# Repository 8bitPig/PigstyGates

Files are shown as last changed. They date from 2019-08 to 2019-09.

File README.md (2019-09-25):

# PigstyGates
teensy based USB-Midi to 24 Jack Gate Out

cc-by-nc-sa 4.0

v1:
Prototype failed! 
After about 2 weeks I stumbled upon the difference between the 74HC595 and 74HCT595.
Next Order will contain a 74HCT595 for retesting. 
Actually I have to guess, that the communication input levels are not enough for the 74HC595.
If this is not the Problem, I will retry with a line driver. 
v1 is still interesting for those who want a minimum part count and 0-5V Output levels. 
v1 code is still to do. Testcode is done and should work. To be shared after testing. 

v2:
-better layout
-correct part names and values
-got rid of SPI / using all 24 GPIO of the small size teensy boards
- TESTED AND WORKING :)
- ebay ADUM3160 USB Isolator since today was only working in theory. <- PROOVED!!!! :) 
- I sent in a sequence with 50% pulse cycle and 1/128 notes at a speed of 120 BPM in all 24 notes simultanously for testing without laggs on a teensy LC.
- code can't be simpler I guess. ^^

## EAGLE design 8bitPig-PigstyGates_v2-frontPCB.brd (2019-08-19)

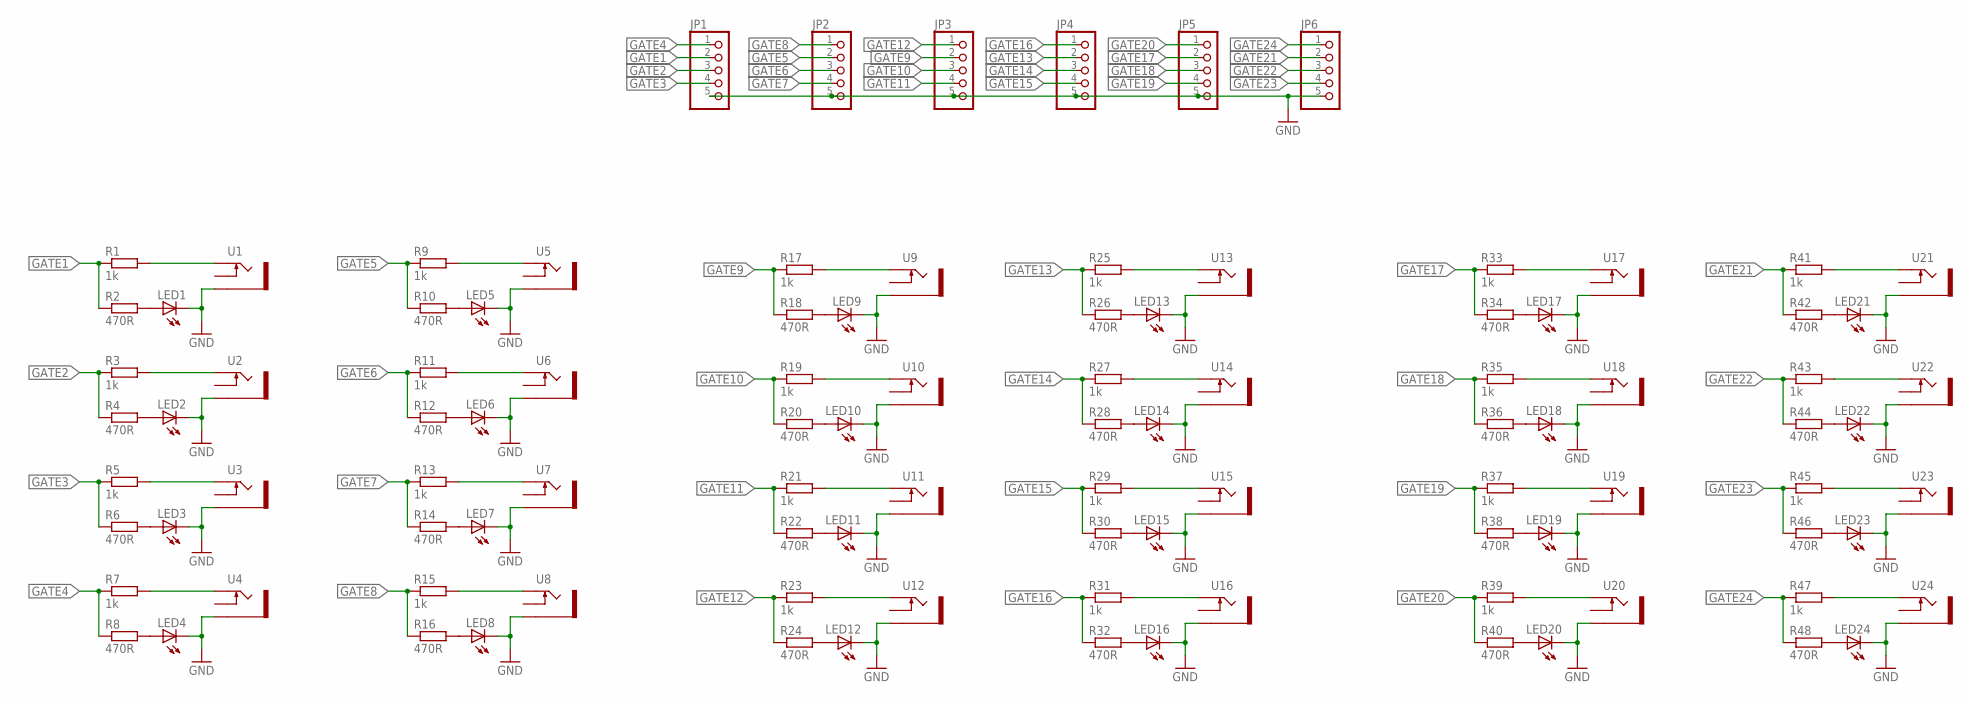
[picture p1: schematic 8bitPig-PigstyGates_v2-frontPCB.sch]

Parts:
JP1, JP2, JP3, JP4, JP5, JP6: PINHD-1X5; 1X05
LED1, LED2, LED3, LED4, LED5, LED6, LED7, LED8, LED9, LED10, LED11, LED12, LED13, LED14, LED15, LED16, LED17, LED18, LED19, LED20, LED21, LED22, LED23, LED24: LED3MM
R1, R3, R5, R7, R9, R11, R13, R15, R17, R19, R21, R23, R25, R27, R29, R31, R33, R35, R37, R39, R41, R43, R45, R47: 1k; R0603
R2, R4, R6, R8, R10, R12, R14, R16, R18, R20, R22, R24, R26, R28, R30, R32, R34, R36, R38, R40, R42, R44, R46, R48: 470R; R0603
U1, U2, U3, U4, U5, U6, U7, U8, U9, U10, U11, U12, U13, U14, U15, U16, U17, U18, U19, U20, U21, U22, U23, U24: THONKICONNNEW; WQP-PJ301M-12_JACK

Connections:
GATE1: JP1.2, R1.1, R2.1
GATE2: JP1.3, R3.1, R4.1
GATE3: JP1.4, R5.1, R6.1
GATE4: JP1.1, R7.1, R8.1
GATE5: JP2.2, R9.1, R10.1
GATE6: JP2.3, R11.1, R12.1
GATE7: JP2.4, R13.1, R14.1
GATE8: JP2.1, R15.1, R16.1
GATE9: JP3.2, R17.1, R18.1
GATE10: JP3.3, R19.1, R20.1
GATE11: JP3.4, R21.1, R22.1
GATE12: JP3.1, R23.1, R24.1
GATE13: JP4.2, R25.1, R26.1
GATE14: JP4.3, R27.1, R28.1
GATE15: JP4.4, R29.1, R30.1
GATE16: JP4.1, R31.1, R32.1
GATE17: JP5.2, R33.1, R34.1
GATE18: JP5.3, R35.1, R36.1
GATE19: JP5.4, R37.1, R38.1
GATE20: JP5.1, R39.1, R40.1
GATE21: JP6.2, R41.1, R42.1
GATE22: JP6.3, R43.1, R44.1
GATE23: JP6.4, R45.1, R46.1
GATE24: JP6.1, R47.1, R48.1
GND: JP1.5, JP2.5, JP3.5, JP4.5, JP5.5, JP6.5, LED1.K (C), LED2.K (C), LED3.K (C), LED4.K (C), LED5.K (C), LED6.K (C), LED7.K (C), LED8.K (C), LED9.K (C), LED10.K (C), LED11.K (C), LED12.K (C), LED13.K (C), LED14.K (C), LED15.K (C), LED16.K (C), LED17.K (C), LED18.K (C), LED19.K (C), LED20.K (C), LED21.K (C), LED22.K (C), LED23.K (C), LED24.K (C), U1.P$3_SLEEVE (SLEEVE), U2.P$3_SLEEVE (SLEEVE), U3.P$3_SLEEVE (SLEEVE), U4.P$3_SLEEVE (SLEEVE), U5.P$3_SLEEVE (SLEEVE), U6.P$3_SLEEVE (SLEEVE), U7.P$3_SLEEVE (SLEEVE), U8.P$3_SLEEVE (SLEEVE), U9.P$3_SLEEVE (SLEEVE), U10.P$3_SLEEVE (SLEEVE), U11.P$3_SLEEVE (SLEEVE), U12.P$3_SLEEVE (SLEEVE), U13.P$3_SLEEVE (SLEEVE), U14.P$3_SLEEVE (SLEEVE), U15.P$3_SLEEVE (SLEEVE), U16.P$3_SLEEVE (SLEEVE), U17.P$3_SLEEVE (SLEEVE), U18.P$3_SLEEVE (SLEEVE), U19.P$3_SLEEVE (SLEEVE), U20.P$3_SLEEVE (SLEEVE), U21.P$3_SLEEVE (SLEEVE), U22.P$3_SLEEVE (SLEEVE), U23.P$3_SLEEVE (SLEEVE), U24.P$3_SLEEVE (SLEEVE)
unnamed: LED1.A, R2.2
unnamed: R1.2, U1.P$1_TIP (TIP)
unnamed: LED2.A, R4.2
unnamed: R3.2, U2.P$1_TIP (TIP)
unnamed: LED3.A, R6.2
unnamed: R5.2, U3.P$1_TIP (TIP)
unnamed: LED4.A, R8.2
unnamed: R7.2, U4.P$1_TIP (TIP)
unnamed: LED5.A, R10.2
unnamed: R9.2, U5.P$1_TIP (TIP)
unnamed: LED6.A, R12.2
unnamed: R11.2, U6.P$1_TIP (TIP)
unnamed: LED7.A, R14.2
unnamed: R13.2, U7.P$1_TIP (TIP)
unnamed: LED8.A, R16.2
unnamed: R15.2, U8.P$1_TIP (TIP)
unnamed: LED9.A, R18.2
unnamed: R17.2, U9.P$1_TIP (TIP)
unnamed: LED10.A, R20.2
unnamed: R19.2, U10.P$1_TIP (TIP)
unnamed: LED11.A, R22.2
unnamed: R21.2, U11.P$1_TIP (TIP)
unnamed: LED12.A, R24.2
unnamed: R23.2, U12.P$1_TIP (TIP)
unnamed: LED13.A, R26.2
unnamed: R25.2, U13.P$1_TIP (TIP)
unnamed: LED14.A, R28.2
unnamed: R27.2, U14.P$1_TIP (TIP)
unnamed: LED15.A, R30.2
unnamed: R29.2, U15.P$1_TIP (TIP)
unnamed: LED17.A, R34.2
unnamed: R33.2, U17.P$1_TIP (TIP)
unnamed: LED16.A, R32.2
unnamed: R31.2, U16.P$1_TIP (TIP)
unnamed: LED18.A, R36.2
unnamed: R35.2, U18.P$1_TIP (TIP)
unnamed: LED19.A, R38.2
unnamed: R37.2, U19.P$1_TIP (TIP)
unnamed: LED20.A, R40.2
unnamed: R39.2, U20.P$1_TIP (TIP)
unnamed: LED21.A, R42.2
unnamed: R41.2, U21.P$1_TIP (TIP)
unnamed: LED22.A, R44.2
unnamed: R43.2, U22.P$1_TIP (TIP)
unnamed: LED23.A, R46.2
unnamed: R45.2, U23.P$1_TIP (TIP)
unnamed: LED24.A, R48.2
unnamed: R47.2, U24.P$1_TIP (TIP)

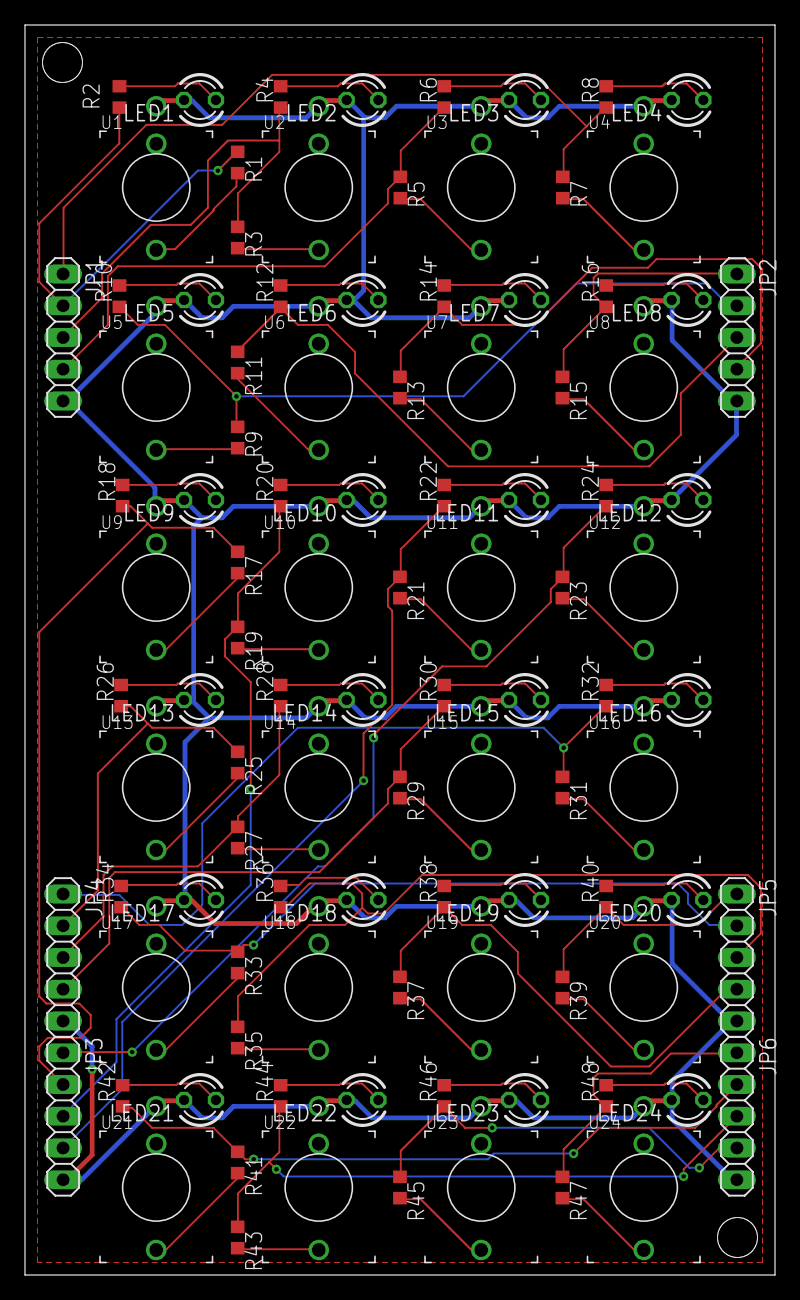
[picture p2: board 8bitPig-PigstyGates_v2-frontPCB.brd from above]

Board: 2 copper layers, 60.0 x 100.0 mm, 102 parts (0 on the bottom side), 73 nets.

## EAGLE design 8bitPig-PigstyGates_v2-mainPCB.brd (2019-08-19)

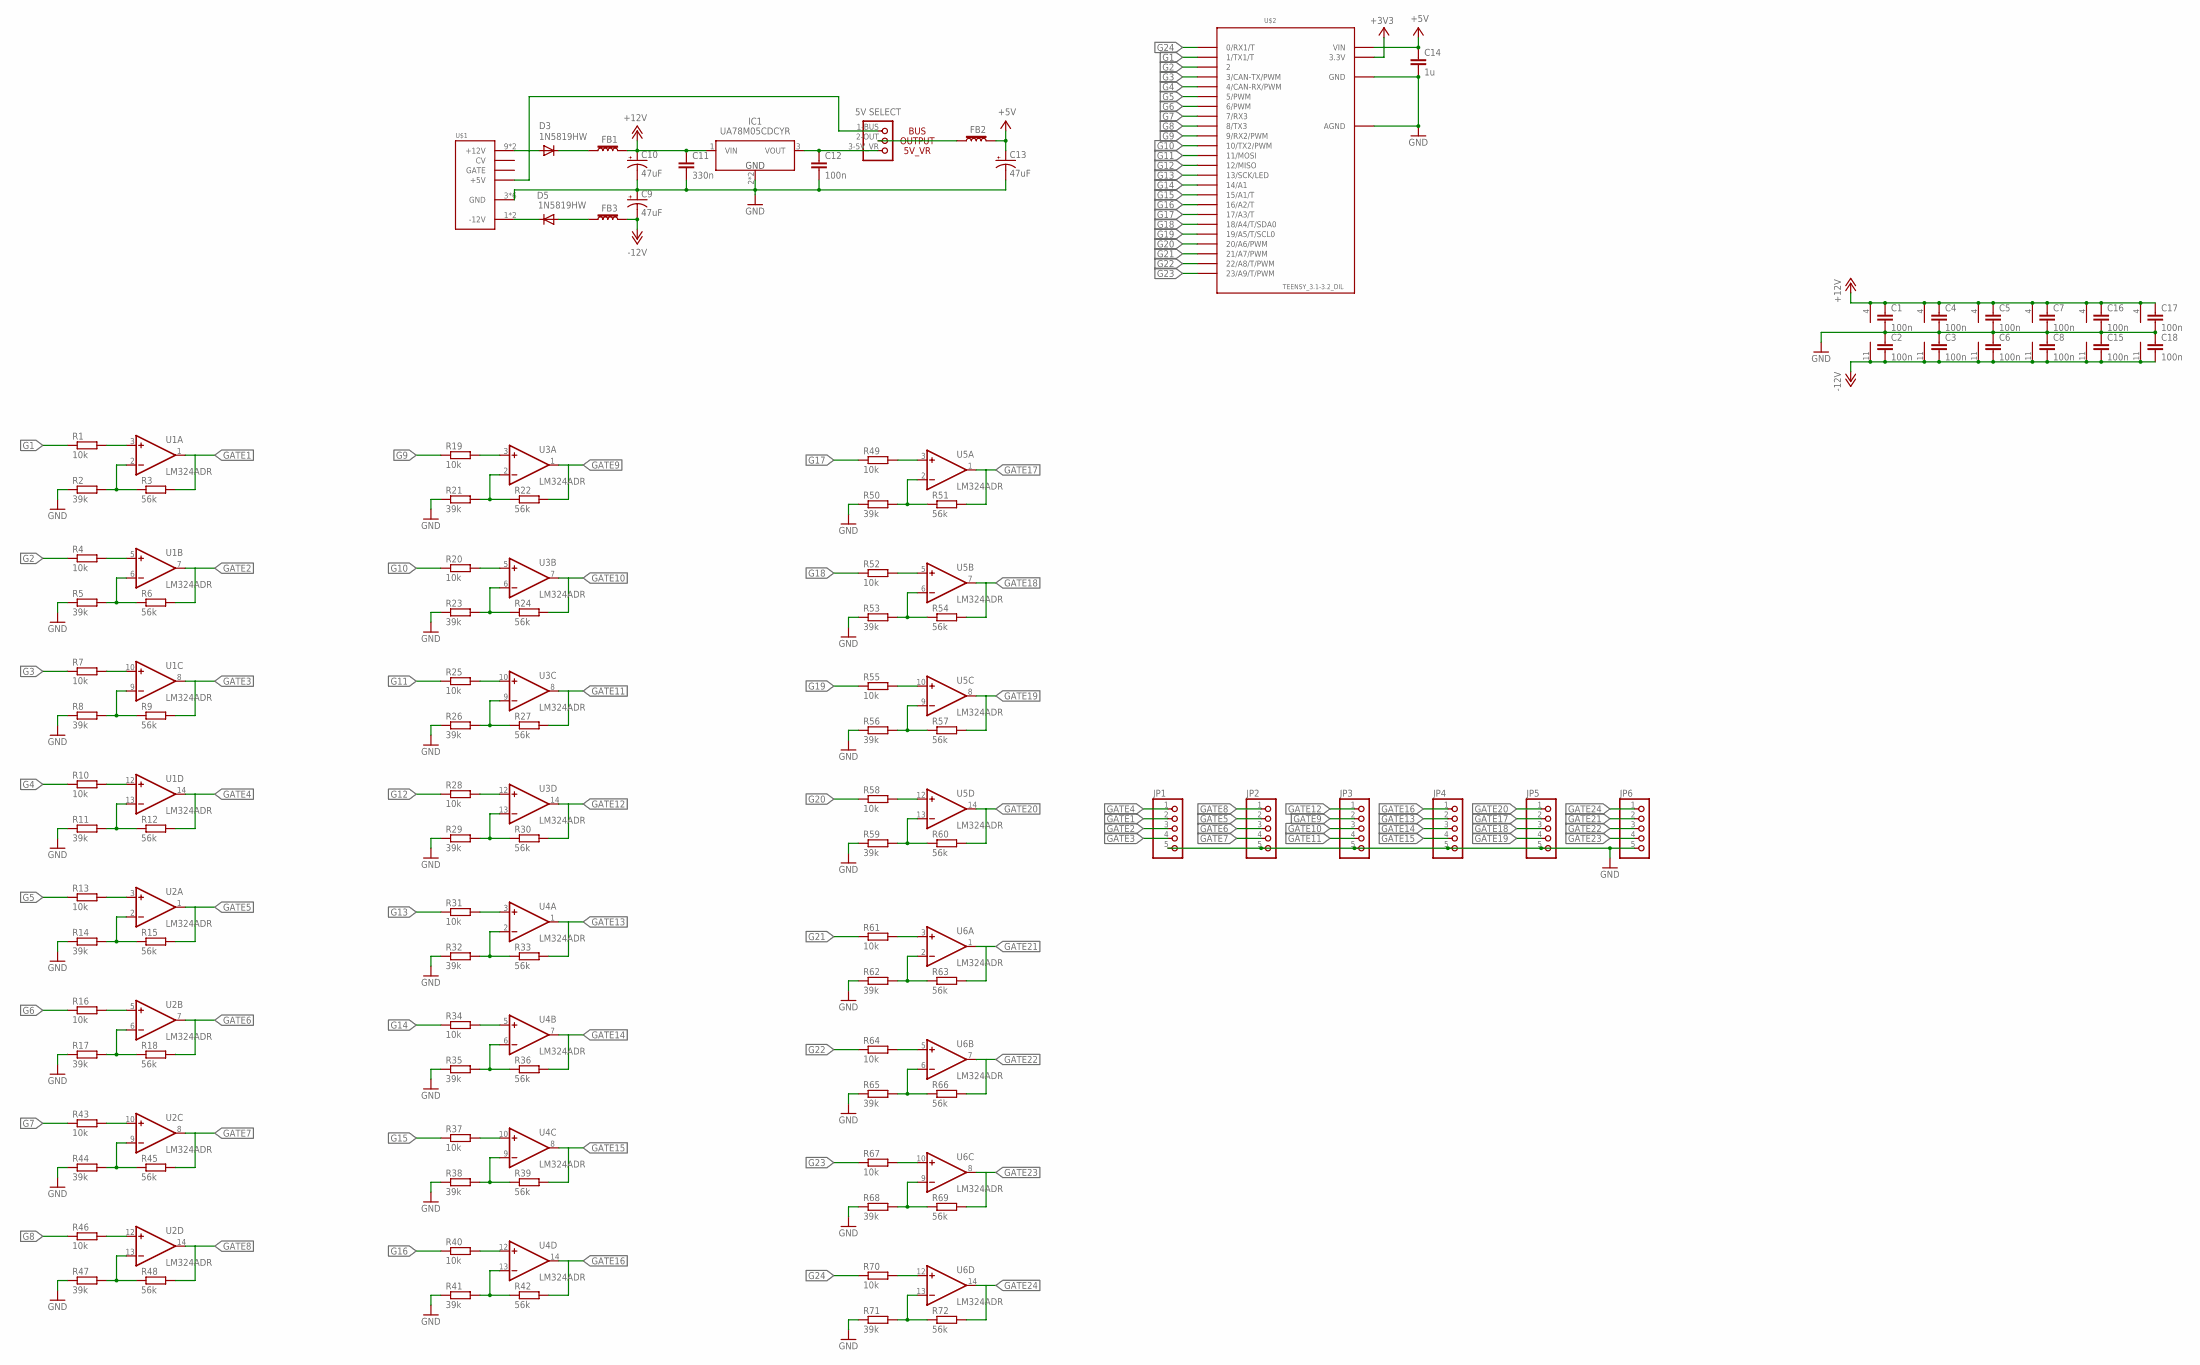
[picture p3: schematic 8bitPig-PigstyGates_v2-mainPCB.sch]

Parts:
C1, C2, C3, C4, C5, C6, C7, C8, C12, C15, C16, C17, C18: 100n; C0603
C9, C10, C13: 47uF; PANASONIC_D
C11: 330n; C0603
C14: 1u; C0603
D3, D5: 1N5819HW; DIODE_SOD123
FB1, FB2, FB3: 30Ω/1.8A; 0603
IC1: UA78M05CDCYR; SOT230P700X180-4N
JP1, JP2, JP3, JP4, JP5, JP6: PINHD-1X5; 1X05
JP_5V: SELECTOR_POWER
R1, R4, R7, R10, R13, R16, R19, R20, R25, R28, R31, R34, R37, R40, R43, R46, R49, R52, R55, R58, R61, R64, R67, R70: 10k; R0603
R2, R5, R8, R11, R14, R17, R21, R23, R26, R29, R32, R35, R38, R41, R44, R47, R50, R53, R56, R59, R62, R65, R68, R71: 39k; R0603
R3, R6, R9, R12, R15, R18, R22, R24, R27, R30, R33, R36, R39, R42, R45, R48, R51, R54, R57, R60, R63, R66, R69, R72: 56k; R0603
U1, U2, U3, U4, U5, U6: LM324ADR; SO14
U$1: POWER; POWER_16
U$2: TEENSY_3.1-3.2_DIL; TEENSY_3.0-3.2&LC_DIL

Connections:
+3V3: U$2.3.3V
+5V: C13.+, C14.1, FB2.2, U$2.VIN
+12V: C1.1, C4.1, C5.1, C7.1, C10.+, C11.1, C16.1, C17.1, FB1.2, IC1.1 (VIN), U1.4 (V+), U2.4 (V+), U3.4 (V+), U4.4 (V+), U5.4 (V+), U6.4 (V+)
-12V: C2.2, C3.2, C6.2, C8.2, C9.-, C15.2, C18.2, FB3.2, U1.11 (V-), U2.11 (V-), U3.11 (V-), U4.11 (V-), U5.11 (V-), U6.11 (V-)
G1: R1.1, U$2.1 (1/TX1/T)
G2: R4.1, U$2.2
G3: R7.1, U$2.3 (3/CAN-TX/PWM)
G4: R10.1, U$2.4 (4/CAN-RX/PWM)
G5: R13.1, U$2.5 (5/PWM)
G6: R16.1, U$2.6 (6/PWM)
G7: R43.1, U$2.7 (7/RX3)
G8: R46.1, U$2.8 (8/TX3)
G9: R19.1, U$2.9 (9/RX2/PWM)
G10: R20.1, U$2.10 (10/TX2/PWM)
G11: R25.1, U$2.11 (11/MOSI)
G12: R28.1, U$2.12 (12/MISO)
G13: R31.1, U$2.13 (13/SCK/LED)
G14: R34.1, U$2.14/A0 (14/A1)
G15: R37.1, U$2.15/A1 (15/A1/T)
G16: R40.1, U$2.16/A2 (16/A2/T)
G17: R49.1, U$2.17/A3 (17/A3/T)
G18: R52.1, U$2.18/A4 (18/A4/T/SDA0)
G19: R55.1, U$2.19/A5 (19/A5/T/SCL0)
G20: R58.1, U$2.20/A6 (20/A6/PWM)
G21: R61.1, U$2.21/A7 (21/A7/PWM)
G22: R64.1, U$2.22/A8 (22/A8/T/PWM)
G23: R67.1, U$2.23/A9 (23/A9/T/PWM)
G24: R70.1, U$2.0 (0/RX1/T)
GATE1: JP1.2, R3.2, U1.1 (OUT)
GATE2: JP1.3, R6.2, U1.7 (OUT)
GATE3: JP1.4, R9.2, U1.8 (OUT)
GATE4: JP1.1, R12.2, U1.14 (OUT)
GATE5: JP2.2, R15.2, U2.1 (OUT)
GATE6: JP2.3, R18.2, U2.7 (OUT)
GATE7: JP2.4, R45.2, U2.8 (OUT)
GATE8: JP2.1, R48.2, U2.14 (OUT)
GATE9: JP3.2, R22.2, U3.1 (OUT)
GATE10: JP3.3, R24.2, U3.7 (OUT)
GATE11: JP3.4, R27.2, U3.8 (OUT)
GATE12: JP3.1, R30.2, U3.14 (OUT)
GATE13: JP4.2, R33.2, U4.1 (OUT)
GATE14: JP4.3, R36.2, U4.7 (OUT)
GATE15: JP4.4, R39.2, U4.8 (OUT)
GATE16: JP4.1, R42.2, U4.14 (OUT)
GATE17: JP5.2, R51.2, U5.1 (OUT)
GATE18: JP5.3, R54.2, U5.7 (OUT)
GATE19: JP5.4, R57.2, U5.8 (OUT)
GATE20: JP5.1, R60.2, U5.14 (OUT)
GATE21: JP6.2, R63.2, U6.1 (OUT)
GATE22: JP6.3, R66.2, U6.7 (OUT)
GATE23: JP6.4, R69.2, U6.8 (OUT)
GATE24: JP6.1, R72.2, U6.14 (OUT)
GND: C1.2, C2.1, C3.1, C4.2, C5.2, C6.1, C7.2, C8.1, C9.+, C10.-, C11.2, C12.2, C13.-, C14.2, C15.1, C16.2, C17.2, C18.1, IC1.2 (GND), IC1.4 (GND), JP1.5, JP2.5, JP3.5, JP4.5, JP5.5, JP6.5, R2.1, R5.1, R8.1, R11.1, R14.1, R17.1, R21.1, R23.1, R26.1, R29.1, R32.1, R35.1, R38.1, R41.1, R44.1, R47.1, R50.1, R53.1, R56.1, R59.1, R62.1, R65.1, R68.1, R71.1, U$1.3 (GND), U$1.4 (GND), U$1.5 (GND), U$1.6 (GND), U$1.7 (GND), U$1.8 (GND), U$2.AGND, U$2.GND
unnamed: R1.2, U1.3 (+IN)
unnamed: R2.2, R3.1, U1.2 (-IN)
unnamed: R4.2, U1.5 (+IN)
unnamed: R5.2, R6.1, U1.6 (-IN)
unnamed: R7.2, U1.10 (+IN)
unnamed: R8.2, R9.1, U1.9 (-IN)
unnamed: R10.2, U1.12 (+IN)
unnamed: R11.2, R12.1, U1.13 (-IN)
unnamed: D3.A, U$1.9 (+12V), U$1.10 (+12V)
unnamed: D5.C, U$1.1 (-12V), U$1.2 (-12V)
unnamed: D5.A, FB3.1
unnamed: D3.C, FB1.1
unnamed: JP_5V.1-BUS, U$1.11 (+5V), U$1.12 (+5V)
unnamed: C12.1, IC1.3 (VOUT), JP_5V.3-5V_VR (3-VR)
unnamed: FB2.1, JP_5V.2-OUT
unnamed: R13.2, U2.3 (+IN)
unnamed: R19.2, U3.3 (+IN)
unnamed: R20.2, U3.5 (+IN)
unnamed: R21.2, R22.1, U3.2 (-IN)
unnamed: R23.2, R24.1, U3.6 (-IN)
unnamed: R25.2, U3.10 (+IN)
unnamed: R26.2, R27.1, U3.9 (-IN)
unnamed: R28.2, U3.12 (+IN)
unnamed: R29.2, R30.1, U3.13 (-IN)
unnamed: R31.2, U4.3 (+IN)
unnamed: R32.2, R33.1, U4.2 (-IN)
unnamed: R34.2, U4.5 (+IN)
unnamed: R35.2, R36.1, U4.6 (-IN)
unnamed: R37.2, U4.10 (+IN)
unnamed: R38.2, R39.1, U4.9 (-IN)
unnamed: R40.2, U4.12 (+IN)
unnamed: R41.2, R42.1, U4.13 (-IN)
unnamed: R14.2, R15.1, U2.2 (-IN)
unnamed: R16.2, U2.5 (+IN)
unnamed: R17.2, R18.1, U2.6 (-IN)
unnamed: R43.2, U2.10 (+IN)
unnamed: R44.2, R45.1, U2.9 (-IN)
unnamed: R46.2, U2.12 (+IN)
unnamed: R47.2, R48.1, U2.13 (-IN)
unnamed: R49.2, U5.3 (+IN)
unnamed: R50.2, R51.1, U5.2 (-IN)
unnamed: R52.2, U5.5 (+IN)
unnamed: R53.2, R54.1, U5.6 (-IN)
unnamed: R55.2, U5.10 (+IN)
unnamed: R56.2, R57.1, U5.9 (-IN)
unnamed: R58.2, U5.12 (+IN)
unnamed: R59.2, R60.1, U5.13 (-IN)
unnamed: R61.2, U6.3 (+IN)
unnamed: R62.2, R63.1, U6.2 (-IN)
unnamed: R64.2, U6.5 (+IN)
unnamed: R65.2, R66.1, U6.6 (-IN)
unnamed: R67.2, U6.10 (+IN)
unnamed: R68.2, R69.1, U6.9 (-IN)
unnamed: R70.2, U6.12 (+IN)
unnamed: R71.2, R72.1, U6.13 (-IN)

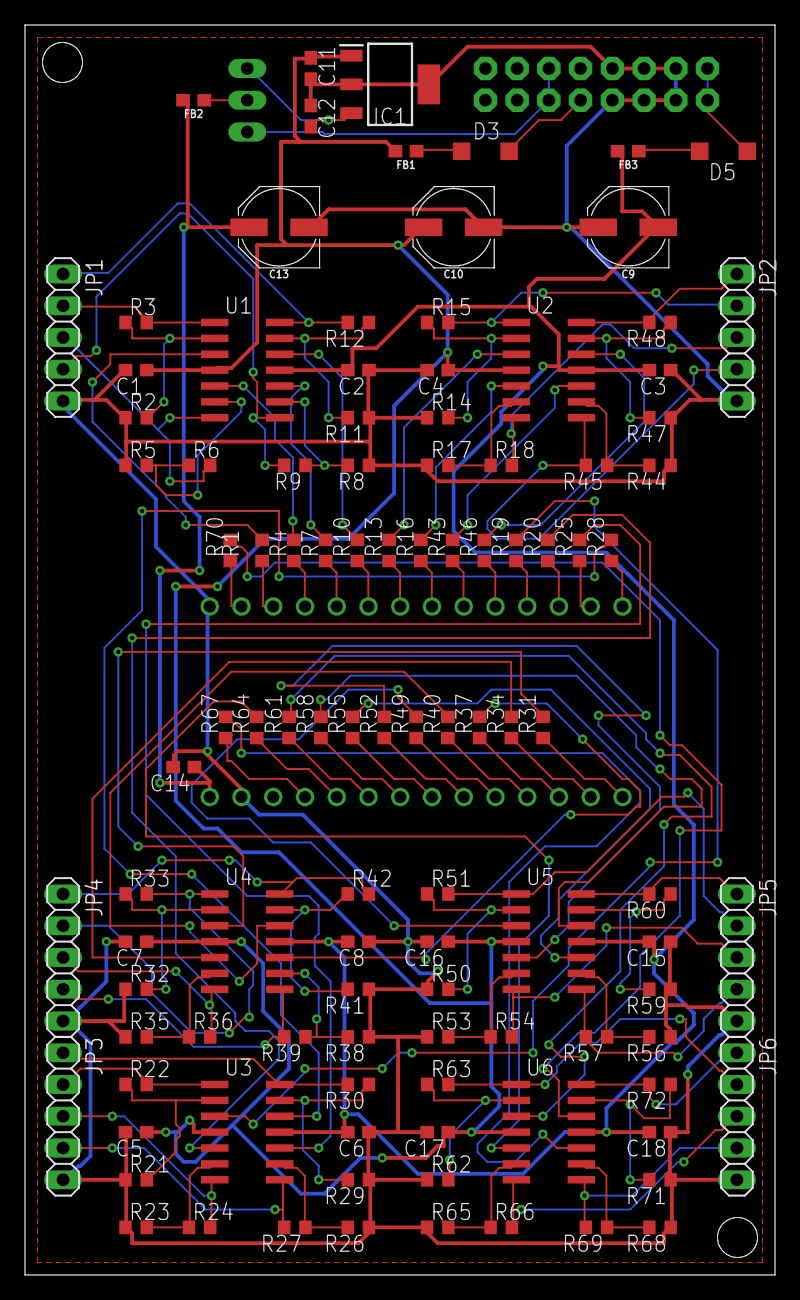
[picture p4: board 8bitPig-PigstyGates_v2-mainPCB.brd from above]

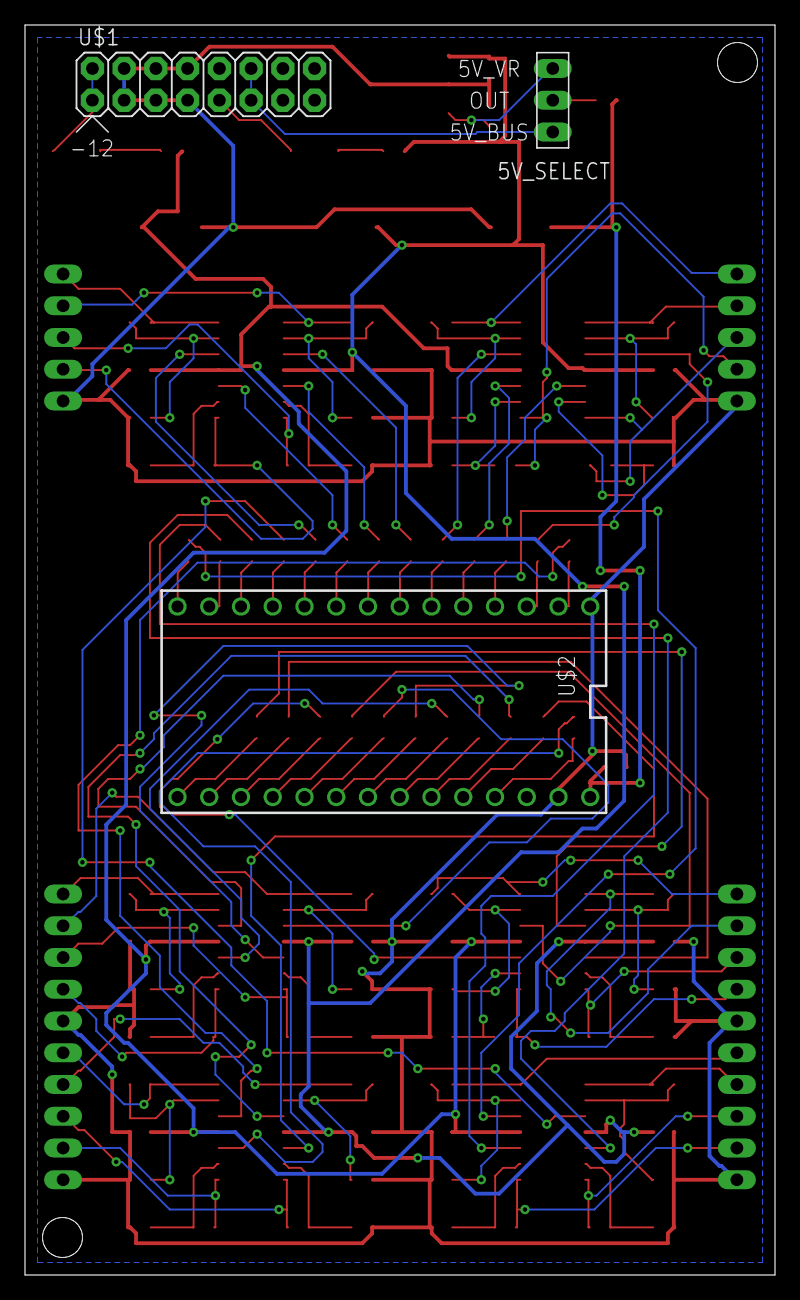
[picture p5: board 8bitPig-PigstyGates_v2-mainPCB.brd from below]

Board: 2 copper layers, 60.0 x 100.0 mm, 111 parts (3 on the bottom side), 107 nets.

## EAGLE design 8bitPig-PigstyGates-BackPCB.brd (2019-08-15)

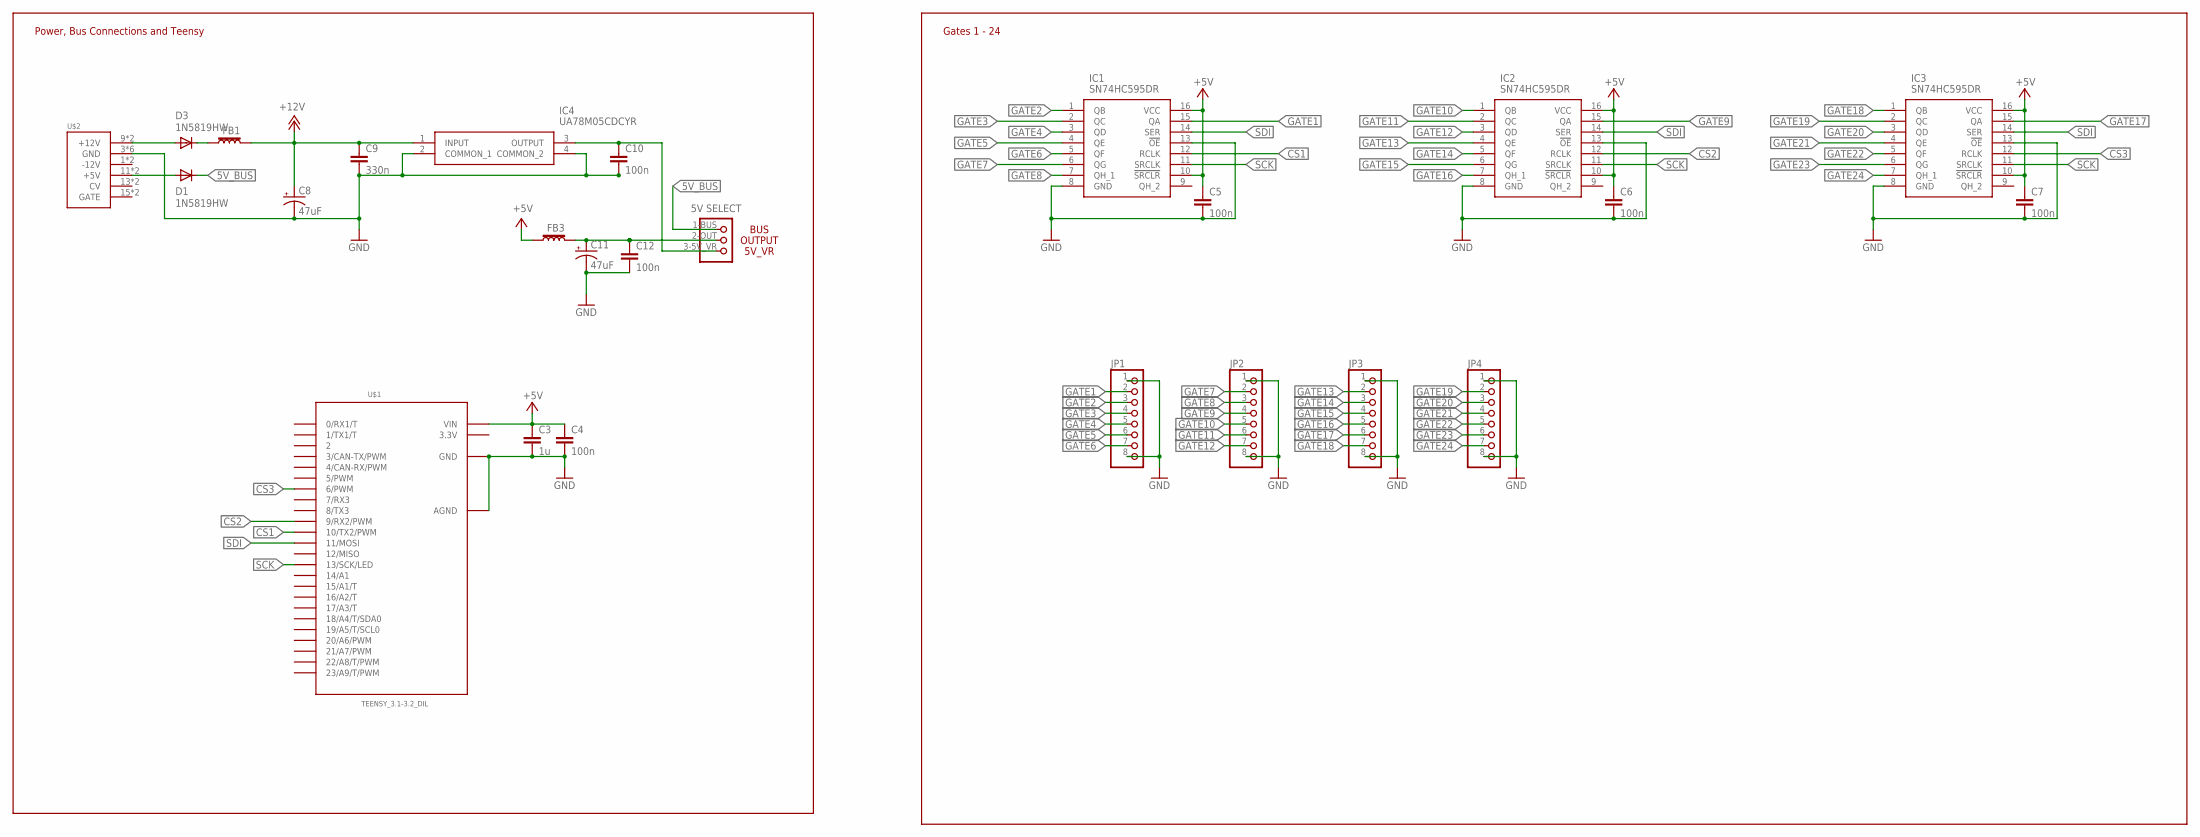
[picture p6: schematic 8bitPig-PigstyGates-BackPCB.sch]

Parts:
C3: 1u; C0603
C4, C5, C6, C7, C10, C12: 100n; C0603
C8, C11: 47uF; PANASONIC_D
C9: 330n; C0603
D1, D3: 1N5819HW; DIODE_SOD123
FB1, FB3: 30Ω/1.8A; 0603
IC1, IC2, IC3: SN74HC595DR; SOIC127P600X175-16N
IC4: UA78M05CDCYR; SOT230P700X180-4N
JP1, JP2, JP3, JP4: PINHD-1X8; 1X08
JP5: SELECTOR_POWER
U$1: TEENSY_3.1-3.2_DIL; TEENSY_3.0-3.2&LC_DIL
U$2: POWER; POWER_16

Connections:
3.3V: U$1.3.3V
5V_BUS: D1.C, JP5.1-BUS
+5V: C3.1, C4.1, C5.1, C6.1, C7.1, FB3.1, IC1.10 (!SRCLR), IC1.16 (VCC), IC2.10 (!SRCLR), IC2.16 (VCC), IC3.10 (!SRCLR), IC3.16 (VCC), U$1.VIN
+12V: C8.+, C9.1, FB1.2, IC4.1 (INPUT)
CS1: IC1.12 (RCLK), U$1.10 (10/TX2/PWM)
CS2: IC2.12 (RCLK), U$1.9 (9/RX2/PWM)
CS3: IC3.12 (RCLK), U$1.6 (6/PWM)
GATE1: IC1.15 (QA), JP1.2
GATE2: IC1.1 (QB), JP1.3
GATE3: IC1.2 (QC), JP1.4
GATE4: IC1.3 (QD), JP1.5
GATE5: IC1.4 (QE), JP1.6
GATE6: IC1.5 (QF), JP1.7
GATE7: IC1.6 (QG), JP2.2
GATE8: IC1.7 (QH_1), JP2.3
GATE9: IC2.15 (QA), JP2.4
GATE10: IC2.1 (QB), JP2.5
GATE11: IC2.2 (QC), JP2.6
GATE12: IC2.3 (QD), JP2.7
GATE13: IC2.4 (QE), JP3.2
GATE14: IC2.5 (QF), JP3.3
GATE15: IC2.6 (QG), JP3.4
GATE16: IC2.7 (QH_1), JP3.5
GATE17: IC3.15 (QA), JP3.6
GATE18: IC3.1 (QB), JP3.7
GATE19: IC3.2 (QC), JP4.2
GATE20: IC3.3 (QD), JP4.3
GATE21: IC3.4 (QE), JP4.4
GATE22: IC3.5 (QF), JP4.5
GATE23: IC3.6 (QG), JP4.6
GATE24: IC3.7 (QH_1), JP4.7
GND: C3.2, C4.2, C5.2, C6.2, C7.2, C8.-, C9.2, C10.2, C11.-, C12.2, IC1.8 (GND), IC1.13 (!OE), IC2.8 (GND), IC2.13 (!OE), IC3.8 (GND), IC3.13 (!OE), IC4.2 (COMMON_1), IC4.4 (COMMON_2), JP1.1, JP1.8, JP2.1, JP2.8, JP3.1, JP3.8, JP4.1, JP4.8, U$1.AGND, U$1.GND, U$2.3 (GND), U$2.4 (GND), U$2.5 (GND), U$2.6 (GND), U$2.7 (GND), U$2.8 (GND)
unnamed: D3.A, U$2.9 (+12V), U$2.10 (+12V)
unnamed: D1.A, U$2.11 (+5V), U$2.12 (+5V)
unnamed: C11.+, C12.1, FB3.2, JP5.2-OUT
unnamed: D3.C, FB1.1
unnamed: C10.1, IC4.3 (OUTPUT), JP5.3-5V_VR (3-VR)
SCK: IC1.11 (SRCLK), IC2.11 (SRCLK), IC3.11 (SRCLK), U$1.13 (13/SCK/LED)
SDI: IC1.14 (SER), IC2.14 (SER), IC3.14 (SER), U$1.11 (11/MOSI)

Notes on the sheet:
Gates 1 - 24
Power, Bus Connections and Teensy

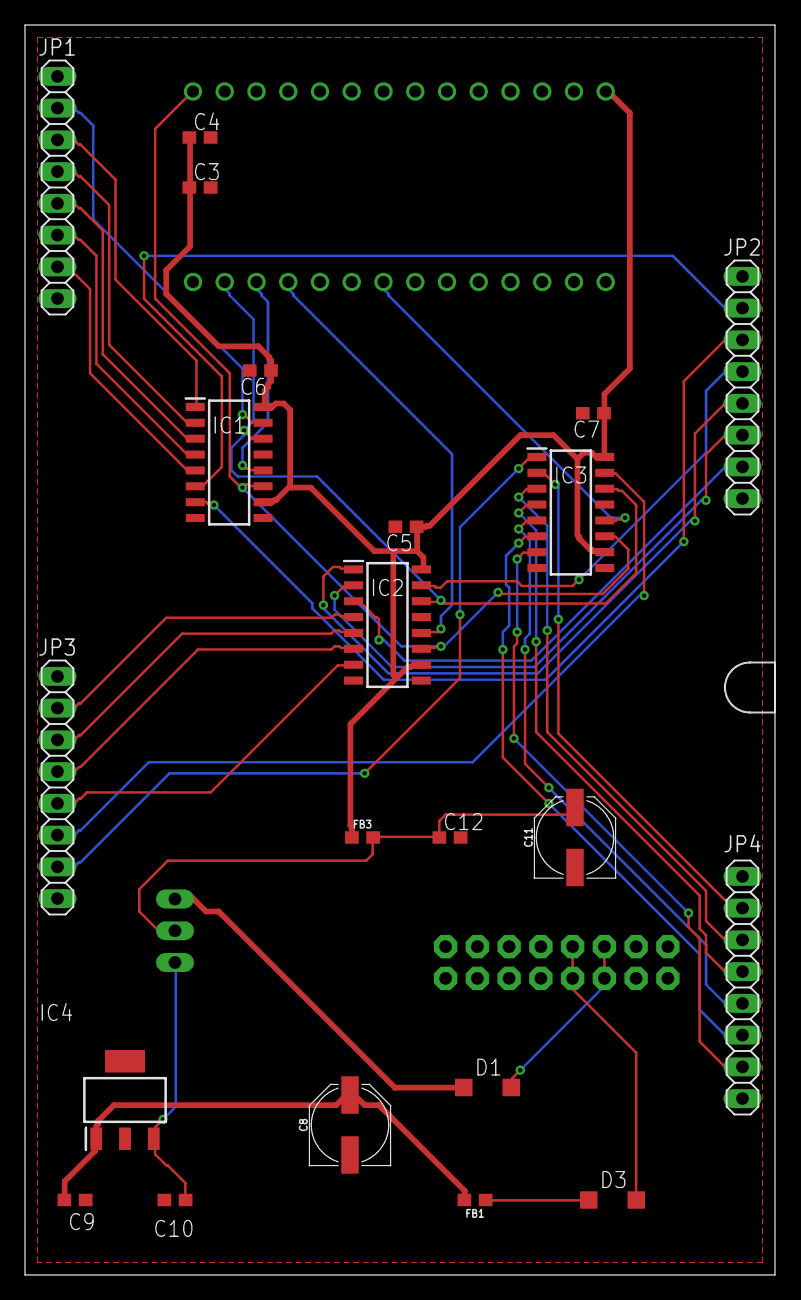
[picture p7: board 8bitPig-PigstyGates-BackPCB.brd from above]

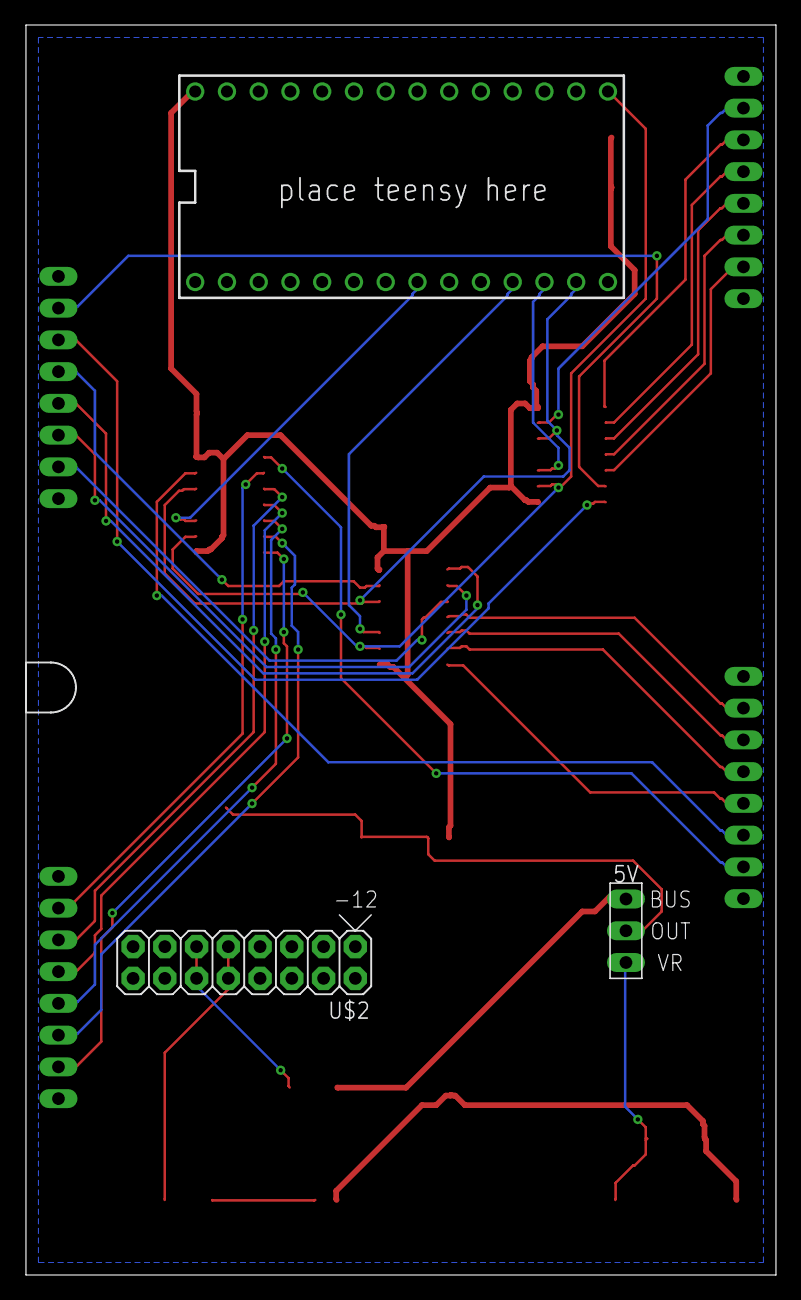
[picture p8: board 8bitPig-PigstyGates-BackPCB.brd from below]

Board: 2 copper layers, 60.0 x 100.0 mm, 26 parts (3 on the bottom side), 38 nets.

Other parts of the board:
U$3: PANEL_CABLE_CUTOUT

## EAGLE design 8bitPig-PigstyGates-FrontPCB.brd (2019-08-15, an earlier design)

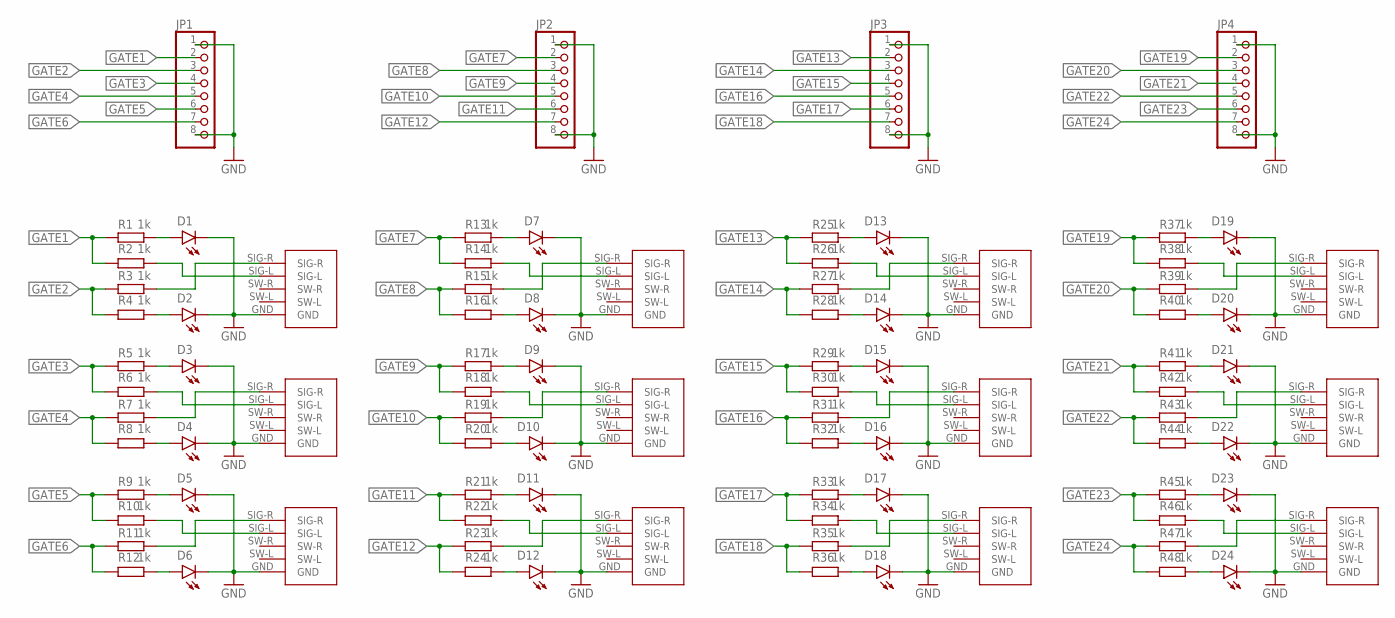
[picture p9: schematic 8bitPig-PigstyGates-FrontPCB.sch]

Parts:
D1, D2, D3, D4, D5, D6, D7, D8, D9, D10, D11, D12, D13, D14, D15, D16, D17, D18, D19, D20, D21, D22, D23, D24: LED3MM; LED_3MM
DUAL_JACK_1, DUAL_JACK_2, DUAL_JACK_3, DUAL_JACK_4, DUAL_JACK_5, DUAL_JACK_6, DUAL_JACK_7, DUAL_JACK_8, DUAL_JACK_9, DUAL_JACK_10, DUAL_JACK_11, DUAL_JACK_12: DUAL_MONO_THONKICONN; DUAL_THONKICONN_MONO
JP1, JP2, JP3, JP4: PINHD-1X8; 1X08
R1, R2, R3, R4, R5, R6, R7, R8, R9, R10, R11, R12, R13, R14, R15, R16, R17, R18, R19, R20, R21, R22, R23, R24, R25, R26, R27, R28, R29, R30, R31, R32, R33, R34, R35, R36, R37, R38, R39, R40, R41, R42, R43, R44, R45, R46, R47, R48: 1k; R0603

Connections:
GATE1: JP1.2, R1.1, R2.1
GATE2: JP1.3, R3.1, R4.1
GATE3: JP1.4, R5.1, R6.1
GATE4: JP1.5, R7.1, R8.1
GATE5: JP1.6, R9.1, R10.1
GATE6: JP1.7, R11.1, R12.1
GATE7: JP2.2, R13.1, R14.1
GATE8: JP2.3, R15.1, R16.1
GATE9: JP2.4, R17.1, R18.1
GATE10: JP2.5, R19.1, R20.1
GATE11: JP2.6, R21.1, R22.1
GATE12: JP2.7, R23.1, R24.1
GATE13: JP3.2, R25.1, R26.1
GATE14: JP3.3, R27.1, R28.1
GATE15: JP3.4, R29.1, R30.1
GATE16: JP3.5, R31.1, R32.1
GATE17: JP3.6, R33.1, R34.1
GATE18: JP3.7, R35.1, R36.1
GATE19: JP4.2, R37.1, R38.1
GATE20: JP4.3, R39.1, R40.1
GATE21: JP4.4, R41.1, R42.1
GATE22: JP4.5, R43.1, R44.1
GATE23: JP4.6, R45.1, R46.1
GATE24: JP4.7, R47.1, R48.1
GND: D1.K (C), D2.K (C), D3.K (C), D4.K (C), D5.K (C), D6.K (C), D7.K (C), D8.K (C), D9.K (C), D10.K (C), D11.K (C), D12.K (C), D13.K (C), D14.K (C), D15.K (C), D16.K (C), D17.K (C), D18.K (C), D19.K (C), D20.K (C), D21.K (C), D22.K (C), D23.K (C), D24.K (C), DUAL_JACK_1.GND, DUAL_JACK_2.GND, DUAL_JACK_3.GND, DUAL_JACK_4.GND, DUAL_JACK_5.GND, DUAL_JACK_6.GND, DUAL_JACK_7.GND, DUAL_JACK_8.GND, DUAL_JACK_9.GND, DUAL_JACK_10.GND, DUAL_JACK_11.GND, DUAL_JACK_12.GND, JP1.1, JP1.8, JP2.1, JP2.8, JP3.1, JP3.8, JP4.1, JP4.8
unnamed: DUAL_JACK_2.SIG-R, R7.2
unnamed: DUAL_JACK_1.SIG-L, R2.2
unnamed: D4.A, R8.2
unnamed: D3.A, R5.2
unnamed: D1.A, R1.2
unnamed: DUAL_JACK_2.SIG-L, R6.2
unnamed: DUAL_JACK_3.SIG-R, R11.2
unnamed: D6.A, R12.2
unnamed: D5.A, R9.2
unnamed: DUAL_JACK_3.SIG-L, R10.2
unnamed: DUAL_JACK_4.SIG-R, R15.2
unnamed: D8.A, R16.2
unnamed: D7.A, R13.2
unnamed: DUAL_JACK_4.SIG-L, R14.2
unnamed: DUAL_JACK_5.SIG-R, R19.2
unnamed: D10.A, R20.2
unnamed: DUAL_JACK_1.SIG-R, R3.2
unnamed: D9.A, R17.2
unnamed: DUAL_JACK_5.SIG-L, R18.2
unnamed: DUAL_JACK_6.SIG-R, R23.2
unnamed: D2.A, R4.2
unnamed: D12.A, R24.2
unnamed: D11.A, R21.2
unnamed: DUAL_JACK_6.SIG-L, R22.2
unnamed: DUAL_JACK_7.SIG-R, R27.2
unnamed: D14.A, R28.2
unnamed: D13.A, R25.2
unnamed: DUAL_JACK_7.SIG-L, R26.2
unnamed: DUAL_JACK_8.SIG-R, R31.2
unnamed: D16.A, R32.2
unnamed: D15.A, R29.2
unnamed: DUAL_JACK_8.SIG-L, R30.2
unnamed: DUAL_JACK_9.SIG-R, R35.2
unnamed: D18.A, R36.2
unnamed: D17.A, R33.2
unnamed: DUAL_JACK_9.SIG-L, R34.2
unnamed: DUAL_JACK_10.SIG-R, R39.2
unnamed: D20.A, R40.2
unnamed: D19.A, R37.2
unnamed: DUAL_JACK_10.SIG-L, R38.2
unnamed: DUAL_JACK_11.SIG-R, R43.2
unnamed: D22.A, R44.2
unnamed: D21.A, R41.2
unnamed: DUAL_JACK_11.SIG-L, R42.2
unnamed: DUAL_JACK_12.SIG-R, R47.2
unnamed: D24.A, R48.2
unnamed: D23.A, R45.2
unnamed: DUAL_JACK_12.SIG-L, R46.2

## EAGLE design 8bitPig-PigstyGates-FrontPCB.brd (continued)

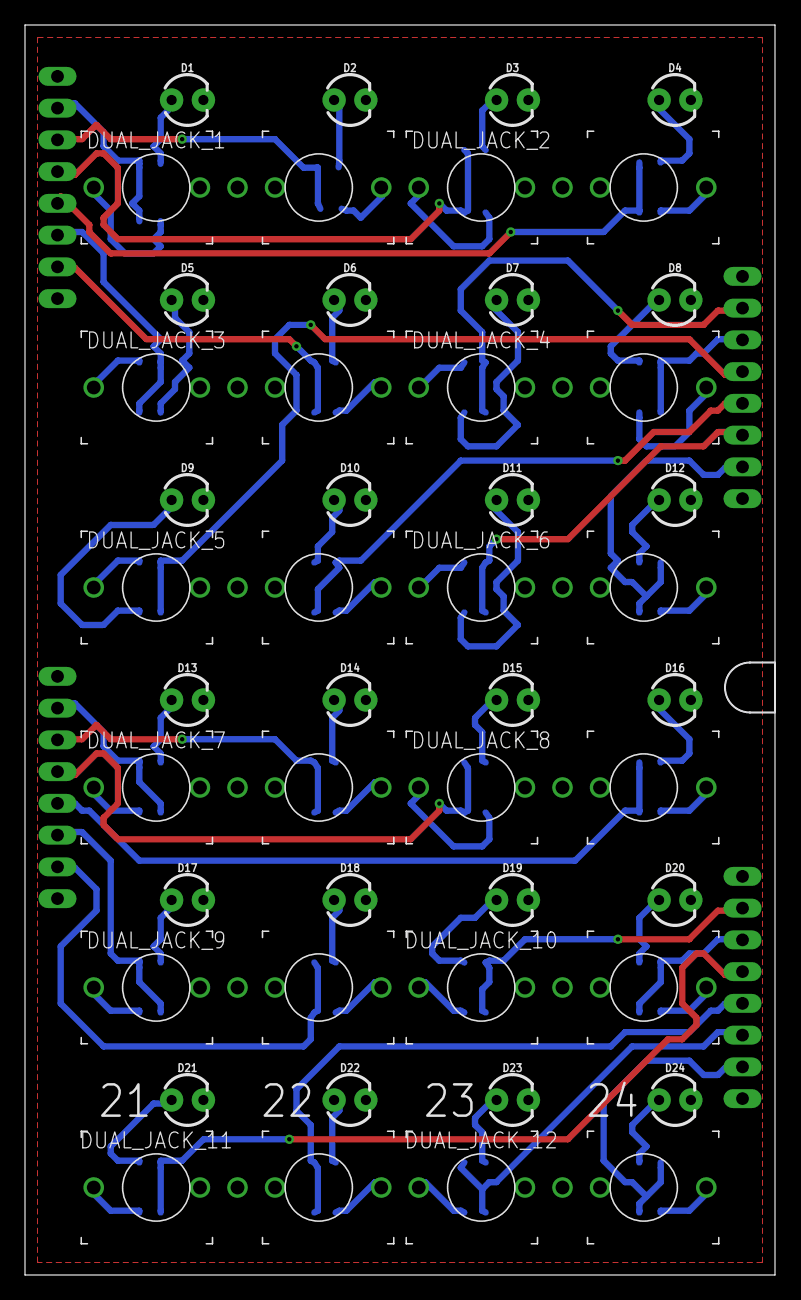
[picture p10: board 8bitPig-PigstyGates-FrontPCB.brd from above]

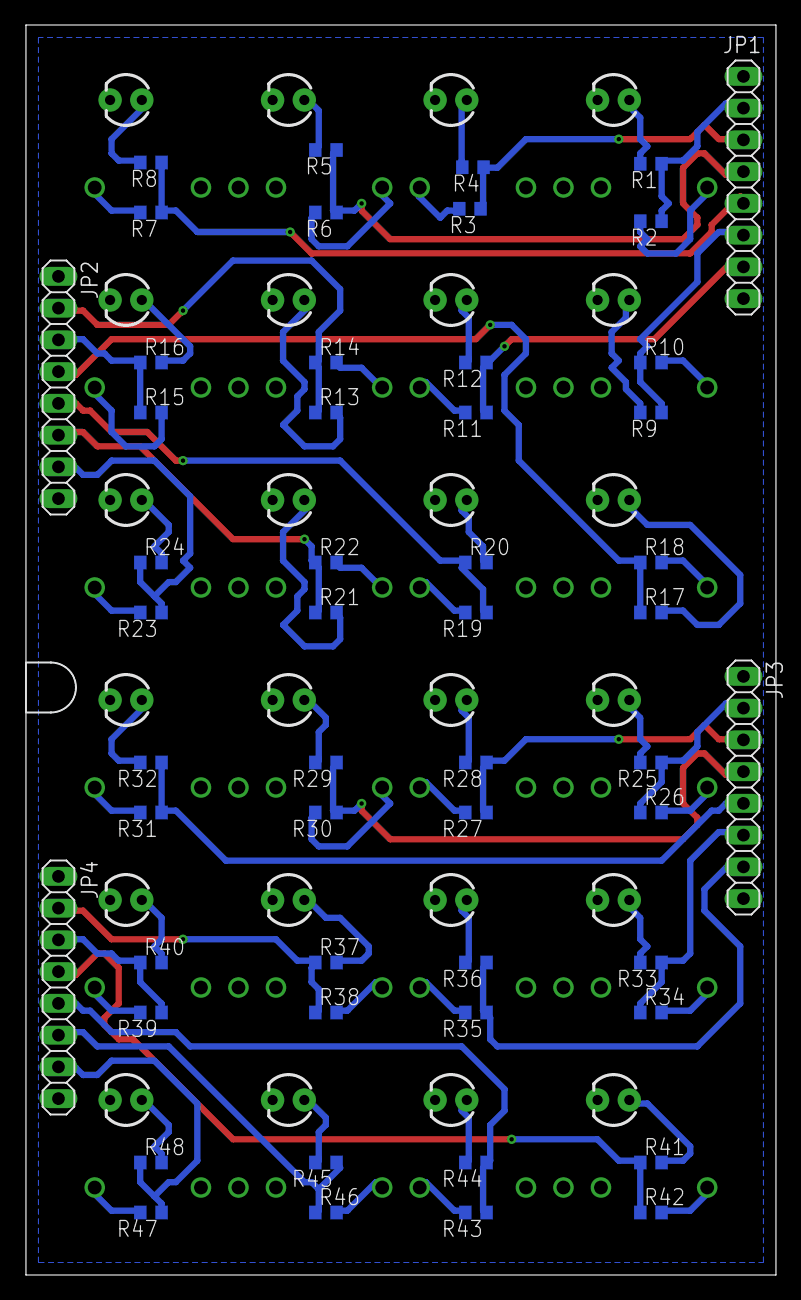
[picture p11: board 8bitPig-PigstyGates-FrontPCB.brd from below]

Board: 2 copper layers, 60.0 x 100.0 mm, 89 parts (52 on the bottom side), 73 nets.

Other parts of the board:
U$1: PANEL_CABLE_CUTOUT

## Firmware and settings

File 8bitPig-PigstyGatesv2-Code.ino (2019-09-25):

void setup()   {   
  for(int i=0;i<24; i++)
  {
     pinMode(i, OUTPUT);
  }
  usbMIDI.setHandleNoteOn(myNoteOn);
  usbMIDI.setHandleNoteOff(myNoteOff);
}

void myNoteOn(byte channel, byte note, byte velocity){
  digitalWriteFast(note % 24 , HIGH);
}

void myNoteOff(byte channel, byte note, byte velocity){
  digitalWriteFast(note % 24 , LOW);
}

void loop()                     
{
  usbMIDI.read();
}

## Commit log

2019-08-19 uploaded v2
    better layout
    better parts. (swapped TL074 for LM324 to drive Gates and LEDs)
    got rid of SPI and connected all 24 Gates to GPIO Pins of the teensy.
    brd still compatible to all teensy small footprint boards. (only the 24 outside PINs used + GND & VIN)
    [8bitPig-PigstyGates_v2-frontPCB.brd, 8bitPig-PigstyGates_v2-frontPCB.sch, 8bitPig-PigstyGates_v2-frontPanel.brd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]
2019-09-25 Add files via upload
    uploaded working hex and ino file
    ino should work for following teensy boards:
    LC, 2.0, 3.0, 3.1, 3.2, 4.0
    (but 4.0 did not work yet because I was not able to select USB-Midi for the Teensy 4.0 boards atm.
    Guess this will be fixed in a future update of Arduino or Teensyduino Software)
    [8bitPig-PigstyGatesv2-Code.ino]

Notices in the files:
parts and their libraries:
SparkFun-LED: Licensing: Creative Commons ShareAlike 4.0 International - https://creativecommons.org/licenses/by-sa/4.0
